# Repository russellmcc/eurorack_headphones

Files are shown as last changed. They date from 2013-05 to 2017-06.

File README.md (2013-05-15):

This is a tested design for a small headphone amp/line output module for eurorack modular synthesizers.

Most of the construction is SMT, with the exception of user-replaceable socketted op-amps.

Please use the BOM.txt to order parts.

This is 5hp and uses 20mA current.

This work is licensed under a [Creative Commons Attribution-ShareAlike 3.0 Unported License.](http://creativecommons.org/licenses/by-sa/3.0/deed.en_US)

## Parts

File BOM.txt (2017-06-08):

Connectors:
2x JP302M-style jacks (available from thonk or modular addict)
2x Neutrik NMJ4HHD2 mono 1/4 inch jacks (J201, J202)
1x Neutrik NMJ6HFD2 stereo 1/4 inch jack (J301)
1x M08x2 eurorack power connector (J401) - 90 degree
2x DIP-8 sockets (IC201, IC301)

Potentiometers:
1x 50K audio taper ALPS RK09L12B0A31 dual pot (P101)

Semiconductors:
1x SOIC-8 LF353D op amp (IC101)
2x DIP-8  LF353N op amp (IC201, IC301)

Capacitors:
3x 0603 .1uF X7R Capacitor (C401, C402, C403)

Resistors:
4x 0603 200k 5% (R101, R102, R301, R302)
8x 0603 100k 5% (R103, R104, R201, R202, R203, R204, R303, R304)
2x 0603   1k 5% (R205, R206)
2x 0603  100 5% (R305, R306)

Mouser Link to Project:
http://www.mouser.com/ProjectManager/ProjectDetail.aspx?AccessID=ae4eb95cf5

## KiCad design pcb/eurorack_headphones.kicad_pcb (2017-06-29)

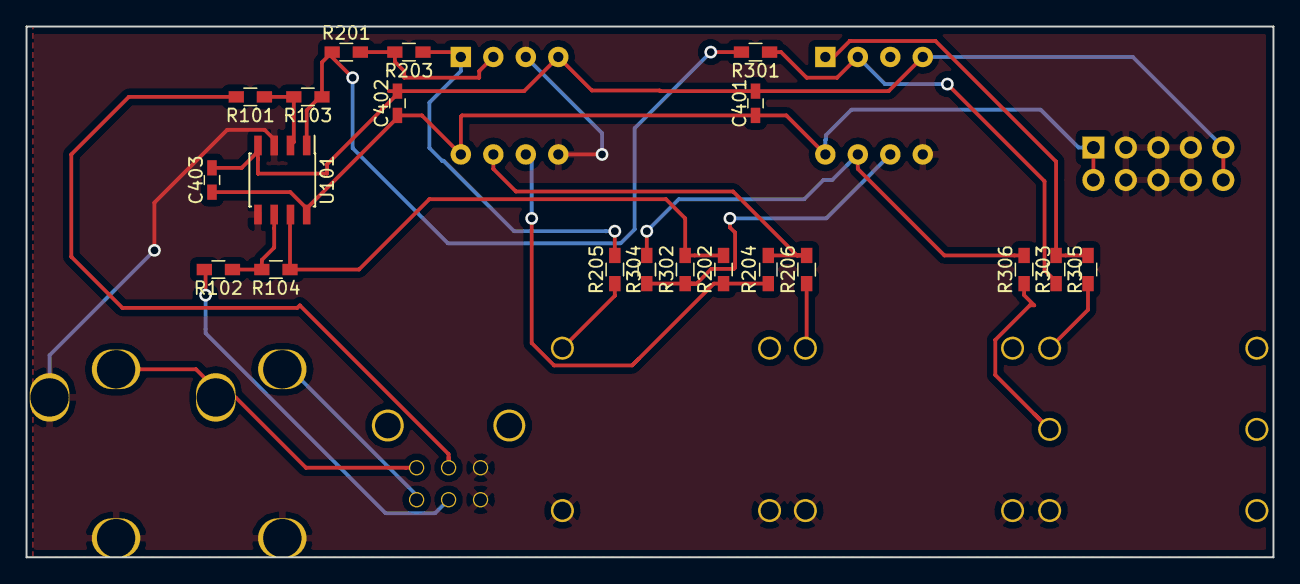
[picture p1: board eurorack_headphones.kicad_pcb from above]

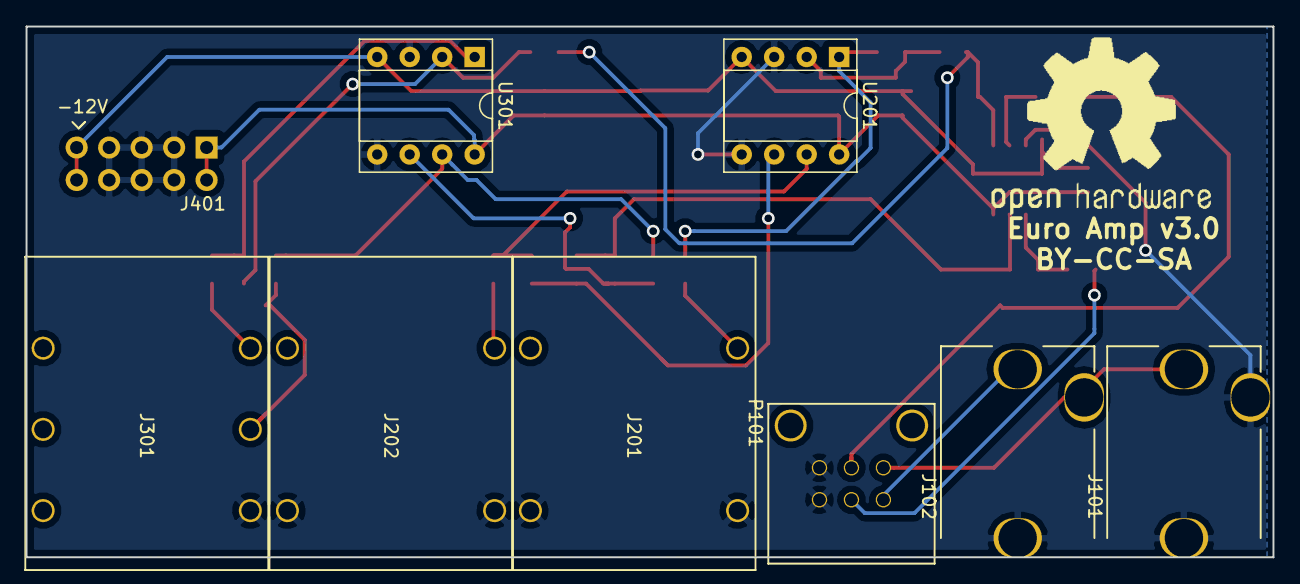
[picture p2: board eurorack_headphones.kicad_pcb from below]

Board: 2 copper layers, 97.5 x 41.5 mm, 29 parts (9 on the bottom side), 23 nets.

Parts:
C401, C402, C403: 0.1uF; C_0603_HandSoldering
J101, J102: JACK_2P; Jack.PJ302M
J201, J202: JACK_2P; Neutrick_NMJ4HHD2
J301: JACK_TRS_6PINS; Neutrick_NMJ4HFD2
J401: EurorackPower; EurorackPower10
P101: POT_Dual 50k; ALPS_RK09_Horizontal
R101, R102, R301, R302: 200k; R_0603_HandSoldering
R103, R104, R201, R202, R203, R204, R303, R304: 100k; R_0603_HandSoldering
R205, R206: 1k; R_0603_HandSoldering
R305, R306: 100; R_0603_HandSoldering
U101: TL072; SOIC-8_3.9x4.9mm_Pitch1.27mm
U201, U301: TL072; DIP-8_W7.62mm_Socket

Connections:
+12V: C401.1, C402.1, C403.1, J401.1, U101.8, U201.8, U301.8
-12V: C401.2, C402.2, C403.2, J401.3, U101.4, U201.4, U301.4
/Left: R103.1, R201.2, R301.2, U101.1
/Right: R104.1, R202.2, R302.2, U101.7
GND: J101.2, J101.3, J102.3, J201.3, J202.3, J301.1, J401.2, P101.3, P101.6, U101.3, U101.5, U201.3, U201.5, U301.3, U301.5
unnamed: J101.1, J102.2, P101.1
unnamed: J102.1, P101.4
unnamed: J201.1, R205.1
unnamed: J202.1, R206.1
unnamed: J301.2, R305.1
unnamed: J301.3, R306.1
unnamed: P101.2, R101.2
unnamed: P101.5, R102.2
unnamed: R101.1, R103.2, U101.2
unnamed: R102.1, R104.2, U101.6
unnamed: R201.1, R203.2, U201.2
unnamed: R202.1, R204.2, U201.6
unnamed: R203.1, R205.2, U201.1
unnamed: R204.1, R206.2, U201.7
unnamed: R301.1, R303.2, U301.2
unnamed: R302.1, R304.2, U301.6
unnamed: R303.1, R305.2, U301.1
unnamed: R304.1, R306.2, U301.7

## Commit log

2013-02-06 initial version of headphone amp
    [headphone.brd, headphone.sch]
2013-02-07 Added gitignore and a BOM
2013-02-07 finished parting out the BOM from mouser
2013-02-14 added silkscreen
    [headphone.brd]
2013-03-14 solder mask!
2013-04-08 fix for backwards volume knob and too-small text
    [headphone.brd, headphone.sch]
2017-06-08 WIP new kicad design
    [eurorack_headphones.kicad_pcb, eurorack_headphones.sch, headphone.brd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]
2017-06-08 Update pcb
    [eurorack_headphones.kicad_pcb, eurorack_headphones.sch]
2017-06-08 Fix for BOM
2017-06-29 Fix errors on board
    [eurorack_headphones.kicad_pcb, eurorack_headphones.sch]
